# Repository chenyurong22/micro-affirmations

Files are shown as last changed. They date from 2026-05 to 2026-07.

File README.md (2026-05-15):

# µAffirmations
A microcontroller-based affection-giving MACHINE!

> [!IMPORTANT]
> This project is currently a work-in-progress, there __will__ be things that don't work, please bear with me will I work out the kinks!

# Table of Contents
- [Usage Guide](#usage-guide)
  - [Hardware](#hardware)
  - [Firmware](#firmware)
- [Project Updates](#project-updates)
- [Copyright and Licensing](#copyright-and-licensing)
- [Contact](#contact)

# Usage Guide
## Hardware
The PCB files can be found [here](/hw/pcb/RevB.zip), be sure of order a solder stencil too(ideally with a stencil unless you love hand-soldering 200+ SMD connections). The [BOM](/hw/pcb/micro-affirmations_BOM.csv) will provide you with a list of parts required. Due to the limited size on the PCB, many of the reference designators have been removed to save space. Because of this, you will likely need to have KiCAD running as you are placing components.

## Firmware
You will need access to an ST-Link programming device and have Platform IO installed via VS code. Once you're ready, upload the code by:
- Cloning the repository
- Open in VS code
- Connect the ST-Link programmer to your computer
- Connect the µAffirmations' programming port to the ST-Link programmer
- Ensure the µAffirmations board is powered
- Open the STM32 for VS Code extention
- Click __Upload__

<!--
### Message customisation
This device allows the user to create their own custom messages to be displayed on the LED matrix, to provide your messages, modify the following code found in [this](/path/to/file.c) file.

For axample:
```c
uint8_t someVar = 0;
```
-->

# Project Updates
## Hardware [RevB](https://github.com/i-Saac-IV/micro-affirmations/tree/v0.9.1)
After hardware tesing the following fixes have been made to the hardware design:
- Supercapcitor charging circuit, now uses a dedecated IC
- LED matrix layout, the LED spacing has been decreased
- LED brightness was assessed and appropriate resistor have been selected
- The overall PCB dimentions have shrunk to 70x40mm

## Hardware [RevA](https://github.com/i-Saac-IV/micro-affirmations/tree/v0.9.0)
Initial hardware design.

# Copyright and Licensing
See [licence](LICENSE) for in depth info.
<!--
This project uses the following third-party libraries:

- Lib ( License)

Copyright and license terms belong to their respective authors.

Contact me if anything here is incorrect.
-->

# Contact
If you'd like to get in touch, feel free to reach out!
<p>
  <a href="https://github.com/i-Saac-IV">
    
  </a>
  <a href="https://www.linkedin.com/in/isaac-pawley/">
    
  </a>
  <a href="https://www.instagram.com/i.saac.0100/">
    
  </a>
  <a href="mailto:75295202+i-Saac-IV@users.noreply.github.com">
    
  </a>
</p>

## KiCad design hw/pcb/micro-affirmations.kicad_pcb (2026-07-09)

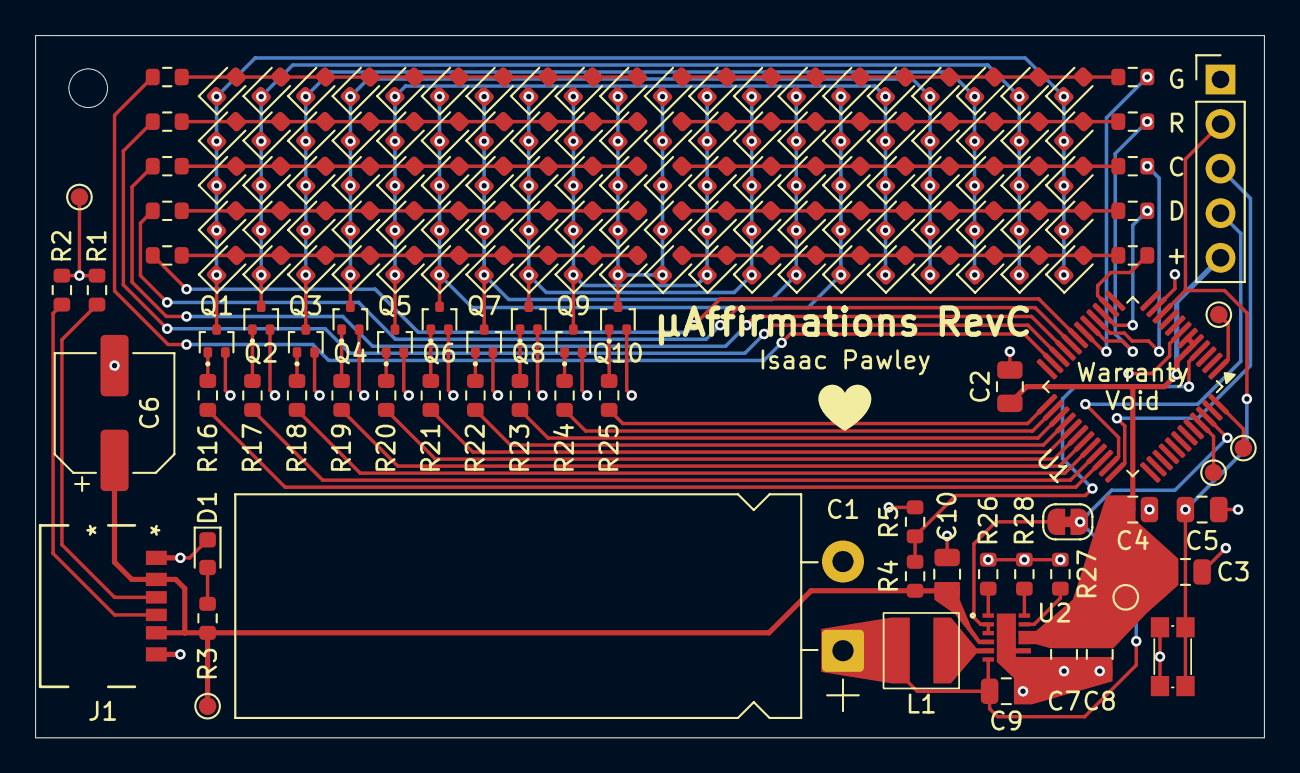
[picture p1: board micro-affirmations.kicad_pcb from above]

Board: 2 copper layers, 70.0 x 40.0 mm, 164 parts (1 on the bottom side), 70 nets.

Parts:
C1: 15F; CP_Radial_L32.0mm_D12.5mm_P5.00mm_Horizontal
C2: 4.7u; C_0805_2012Metric
C3, C4, C5: 100n; C_0805_2012Metric
C6: 100u; CP_Elec_6.3x5.4_Nichicon
C7, C8, C9, C10: 10u; C_0805_2012Metric
D1: CHARGE; D_0603_1608Metric
D5, D6, D7, D8, D9, D10, D11, D12, D13, D14, D15, D16, D17, D18, D19, D20, D21, D22, D23, D24, D25, D26, D27, D28, D29, D30, D31, D32, D33, D34, D35, D36, D37, D38, D39, D40, D41, D42, D43, D44, D45, D46, D47, D48, D49, D50, D51, D52, D53, D54, D55, D56, D57, D58, D59, D60, D61, D62, D63, D64, D65, D66, D67, D68, D69, D70, D71, D72, D73, D74, D75, D76, D77, D78, D79, D80, D81, D82, D83, D84, D85, D86, D87, D88, D89, D90, D91, D92, D93, D94, D95, D96, D97, D98, D99, D100, D101, D102, D103, D104: LED; D_0603_1608Metric
H1: MountingHole; MountingHole_2.2mm_M2
J1: USBC; 2171750001_MOL
J2: DEBUG; PinHeader_1x05_P2.54mm_Vertical
JP1: SolderJumper_2_Bridged; SolderJumper-2_P1.3mm_Bridged_RoundedPad1.0x1.5mm
L1: 2.2u; L_1616_4040Metric
Q1, Q2, Q3, Q4, Q5, Q6, Q7, Q8, Q9, Q10: NCH; SOT-416
R1, R2, R4: 5.1k; R_0603_1608Metric
R3: 1.5k; R_0603_1608Metric
R5: 10k; R_0603_1608Metric
R6, R7, R8, R9, R10, R11, R12, R13, R14, R15: 820; R_0603_1608Metric
R16, R17, R18, R19, R20, R21, R22, R23, R24, R25: 100; R_0603_1608Metric
R26: 4.75k; R_0603_1608Metric
R27: 75.0k; R_0603_1608Metric
R28: 13.0k; R_0603_1608Metric
SW1: RST; TL1030_A
TP2, TP3, TP4, TP5, TP6, TP7, TP8: TestPoint; TestPoint_Pad_D1.0mm
U1: STM32C031C6Tx; LQFP-48_7x7mm_P0.5mm
U2: TPS61094; WSON_94DSSR_TEX

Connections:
+3V3: C2.1, C3.1, C4.1, C7.1, C8.1, J2.5, TP3.1 (1_1), U1.5 (VREF+), U1.6 (VDD), U2.9 (VOUT), U2.10 (VOUT)
+5V: C6.1, C10.1, J1.A9 (VBUS), J1.B9 (VBUS), R3.1, R4.2, TP2.1 (1_1), U2.4 (VIN)
/CHARGE_SENSE: R4.1, R5.2, U1.4 (PF3)
/DEBUG_SWCLK: J2.3, U1.36 (PA14)
/DEBUG_SWDIO: J2.4, U1.35 (PA13)
/MATRIX_A0: R6.1, U1.23 (PB11)
/MATRIX_A1: R7.1, U1.22 (PB10)
/MATRIX_A2: R8.1, U1.21 (PB2)
/MATRIX_A3: R9.1, U1.20 (PB1)
/MATRIX_A4: R10.1, U1.19 (PB0)
/MATRIX_A5: R11.1, U1.18 (PA7)
/MATRIX_A6: R12.1, U1.17 (PA6)
/MATRIX_A7: R13.1, U1.16 (PA5)
/MATRIX_A8: R14.1, U1.15 (PA4)
/MATRIX_A9: R15.1, U1.14 (PA3)
/MATRIX_K0: R16.1, U1.34 (PA12)
/MATRIX_K1: R17.1, U1.33 (PA11)
/MATRIX_K2: R18.1, U1.32 (PA10)
/MATRIX_K3: R19.1, U1.31 (PC7)
/MATRIX_K4: R20.1, U1.30 (PC6)
/MATRIX_K5: R21.1, U1.29 (PA9)
/MATRIX_K6: R22.1, U1.28 (PA8)
/MATRIX_K7: R23.1, U1.27 (PB15)
/MATRIX_K8: R24.1, U1.26 (PB14)
/MATRIX_K9: R25.1, U1.25 (PB13)
/NRST: C5.1, J2.2, SW1.2, U1.10 (PF2)
CAP_VOLT: C1.1, C9.1, JP1.1 (A), L1.2, U1.46 (PB7), U2.6 (SUP)
GND: C1.2, C2.2, C3.2, C4.2, C5.2, C6.2, C7.2, C8.2, C9.2, C10.2, D1.1 (K), J1.A12 (GND), J1.B12 (GND), J2.1, Q1.2 (S), Q2.2 (S), Q3.2 (S), Q4.2 (S), Q5.2 (S), Q6.2 (S), Q7.2 (S), Q8.2 (S), Q9.2 (S), Q10.2 (S), R1.2, R2.2, R5.1, R26.1, R27.1, R28.1, SW1.1, TP8.1 (1_1), U1.7 (VSS), U2.7 (PGND), U2.8 (AGND), U2.13
unnamed: D1.2 (A), R3.2
unnamed: D5.2 (A), D6.2 (A), D7.2 (A), D8.2 (A), D9.2 (A), D10.2 (A), D11.2 (A), D12.2 (A), D13.2 (A), D14.2 (A), R6.2
unnamed: D10.1 (K), D20.1 (K), D30.1 (K), D40.1 (K), D50.1 (K), D60.1 (K), D70.1 (K), D80.1 (K), D90.1 (K), D100.1 (K), Q6.3 (D)
unnamed: D15.2 (A), D16.2 (A), D17.2 (A), D18.2 (A), D19.2 (A), D20.2 (A), D21.2 (A), D22.2 (A), D23.2 (A), D24.2 (A), R7.2
unnamed: D5.1 (K), D15.1 (K), D25.1 (K), D35.1 (K), D45.1 (K), D55.1 (K), D65.1 (K), D75.1 (K), D85.1 (K), D95.1 (K), Q1.3 (D)
unnamed: D6.1 (K), D16.1 (K), D26.1 (K), D36.1 (K), D46.1 (K), D56.1 (K), D66.1 (K), D76.1 (K), D86.1 (K), D96.1 (K), Q2.3 (D)
unnamed: D7.1 (K), D17.1 (K), D27.1 (K), D37.1 (K), D47.1 (K), D57.1 (K), D67.1 (K), D77.1 (K), D87.1 (K), D97.1 (K), Q3.3 (D)
unnamed: D8.1 (K), D18.1 (K), D28.1 (K), D38.1 (K), D48.1 (K), D58.1 (K), D68.1 (K), D78.1 (K), D88.1 (K), D98.1 (K), Q4.3 (D)
unnamed: D9.1 (K), D19.1 (K), D29.1 (K), D39.1 (K), D49.1 (K), D59.1 (K), D69.1 (K), D79.1 (K), D89.1 (K), D99.1 (K), Q5.3 (D)
unnamed: D25.2 (A), D26.2 (A), D27.2 (A), D28.2 (A), D29.2 (A), D30.2 (A), D31.2 (A), D32.2 (A), D33.2 (A), D34.2 (A), R8.2
unnamed: D35.2 (A), D36.2 (A), D37.2 (A), D38.2 (A), D39.2 (A), D40.2 (A), D41.2 (A), D42.2 (A), D43.2 (A), D44.2 (A), R9.2
unnamed: D45.2 (A), D46.2 (A), D47.2 (A), D48.2 (A), D49.2 (A), D50.2 (A), D51.2 (A), D52.2 (A), D53.2 (A), D54.2 (A), R10.2
unnamed: D55.2 (A), D56.2 (A), D57.2 (A), D58.2 (A), D59.2 (A), D60.2 (A), D61.2 (A), D62.2 (A), D63.2 (A), D64.2 (A), R11.2
unnamed: D65.2 (A), D66.2 (A), D67.2 (A), D68.2 (A), D69.2 (A), D70.2 (A), D71.2 (A), D72.2 (A), D73.2 (A), D74.2 (A), R12.2
unnamed: D75.2 (A), D76.2 (A), D77.2 (A), D78.2 (A), D79.2 (A), D80.2 (A), D81.2 (A), D82.2 (A), D83.2 (A), D84.2 (A), R13.2
unnamed: D85.2 (A), D86.2 (A), D87.2 (A), D88.2 (A), D89.2 (A), D90.2 (A), D91.2 (A), D92.2 (A), D93.2 (A), D94.2 (A), R14.2
unnamed: D95.2 (A), D96.2 (A), D97.2 (A), D98.2 (A), D99.2 (A), D100.2 (A), D101.2 (A), D102.2 (A), D103.2 (A), D104.2 (A), R15.2
unnamed: D11.1 (K), D21.1 (K), D31.1 (K), D41.1 (K), D51.1 (K), D61.1 (K), D71.1 (K), D81.1 (K), D91.1 (K), D101.1 (K), Q7.3 (D)
unnamed: D12.1 (K), D22.1 (K), D32.1 (K), D42.1 (K), D52.1 (K), D62.1 (K), D72.1 (K), D82.1 (K), D92.1 (K), D102.1 (K), Q8.3 (D)
unnamed: D13.1 (K), D23.1 (K), D33.1 (K), D43.1 (K), D53.1 (K), D63.1 (K), D73.1 (K), D83.1 (K), D93.1 (K), D103.1 (K), Q9.3 (D)
unnamed: D14.1 (K), D24.1 (K), D34.1 (K), D44.1 (K), D54.1 (K), D64.1 (K), D74.1 (K), D84.1 (K), D94.1 (K), D104.1 (K), Q10.3 (D)
unnamed: J1.A5 (CC1), R1.1
unnamed: J1.B5 (CC2), R2.1
unnamed: JP1.2 (B), U2.2 (MODE), U2.3 (EN)
unnamed: Q1.1 (G), R16.2
unnamed: Q2.1 (G), R17.2
unnamed: Q3.1 (G), R18.2
unnamed: Q4.1 (G), R19.2
unnamed: Q5.1 (G), R20.2
unnamed: Q6.1 (G), R21.2
unnamed: Q7.1 (G), R22.2
unnamed: Q8.1 (G), R23.2
unnamed: Q9.1 (G), R24.2
unnamed: Q10.1 (G), R25.2
unnamed: TP7.1 (1_1), U1.11 (PA0)
unnamed: TP5.1 (1_1), U1.45 (PB6)
unnamed: TP4.1 (1_1), U1.48 (PB9)
unnamed: TP6.1 (1_1), U1.1 (PC13)
unnamed: R27.2, U2.11 (ICHG)
unnamed: R26.2, U2.1 (OSEL)
unnamed: L1.1, U2.5 (SW)
unnamed: R28.2, U2.12 (VCHG)

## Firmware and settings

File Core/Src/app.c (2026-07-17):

/*

File:   app.h
Author: Isaac Pawley

*/

#include "app.h"

#include "adc.h"
#include "stm32c0xx_hal.h"

typedef enum
{
    ADC_RANDOM,
    ADC_CAP_VOLT
} ADC_Input_t;

uint16_t ADC_Read(ADC_Input_t input)
{
    uint16_t random_value = 0;
    uint16_t cap_voltage_value = 0;

    HAL_ADC_Start(&hadc1);

    // Rank 1: PA1 RANDOM
    if (HAL_ADC_PollForConversion(&hadc1, 10) == HAL_OK)
    {
        random_value = HAL_ADC_GetValue(&hadc1);
    }

    // Rank 2: PB7 CAP_VOLT
    if (HAL_ADC_PollForConversion(&hadc1, 10) == HAL_OK)
    {
        cap_voltage_value = HAL_ADC_GetValue(&hadc1);
    }

    HAL_ADC_Stop(&hadc1);

    if (input == ADC_RANDOM)
    {
        return random_value;
    }
    else
    {
        return cap_voltage_value;
    }
}

#include "matrix.h"
#include "nanoGL.h"

void app_main(void) {

    uint32_t now = 0;
    uint32_t next = 0;

    nanoGL_clear();

    static int16_t scrollX = PHYSICAL_COLS;

    while (1) {
        matrix_updateMultiplex();

        if (HAL_GetTick() > next) {
            next = HAL_GetTick() + 75;
            nanoGL_clear();

            nanoGL_drawString(scrollX, 0, "Here is a long message...", &Font_5x5);
            scrollX--;
            
            if (scrollX < -nanoGL_stringWidth("Here is a long message...", &Font_5x5)) {
                scrollX = PHYSICAL_COLS;
            }
        }

        now = HAL_GetTick();
        while (HAL_GetTick() < now + 1) {};
    }    
}

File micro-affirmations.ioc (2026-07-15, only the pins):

Mcu.UserName=STM32C031C6Tx
PA1.GPIO_Label=RANDOM
PA1.Signal=ADC1_IN1
PA10.GPIO_Label=MATRIX_K2
PA10.Signal=GPIO_Output
PA13.Signal=DEBUG_SWDIO
PA14-BOOT0.Signal=DEBUG_SWCLK
PA3.GPIO_Label=MATRIX_A9
PA3.Signal=GPIO_Output
PA4.GPIO_Label=MATRIX_A8
PA4.Signal=GPIO_Output
PA5.GPIO_Label=MATRIX_A7
PA5.Signal=GPIO_Output
PA6.GPIO_Label=MATRIX_A6
PA6.Signal=GPIO_Output
PA7.GPIO_Label=MATRIX_A5
PA7.Signal=GPIO_Output
PA8.GPIO_Label=MATRIX_K6
PA8.Signal=GPIO_Output
PA9.GPIO_Label=MATRIX_K5
PA9.Signal=GPIO_Output
PB0.GPIO_Label=MATRIX_A4
PB0.Signal=GPIO_Output
PB1.GPIO_Label=MATRIX_A3
PB1.Signal=GPIO_Output
PB10.GPIO_Label=MATRIX_A1
PB10.Signal=GPIO_Output
PB11.GPIO_Label=MATRIX_A0
PB11.Signal=GPIO_Output
PB13.GPIO_Label=MATRIX_K9
PB13.Signal=GPIO_Output
PB14.GPIO_Label=MATRIX_K8
PB14.Signal=GPIO_Output
PB15.GPIO_Label=MATRIX_K7
PB15.Signal=GPIO_Output
PB2.GPIO_Label=MATRIX_A2
PB2.Signal=GPIO_Output
PB7.GPIO_Label=CAP_VOLT
PB7.Signal=GPIO_Analog
PC6.GPIO_Label=MATRIX_K4
PC6.Signal=GPIO_Output
PC7.GPIO_Label=MATRIX_K3
PC7.Signal=GPIO_Output
PF3.GPIO_Label=CHARGE_SENSE
PF3.Signal=GPIO_Input

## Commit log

2026-05-11 chore: added charger footprints
2026-05-11 chore: updated schematic to have correctly sized current limiting resistors
    [led-matrix.kicad_sch]
2026-05-11 chore: redesigned pcb, new capacitor charger and smaller matrix
    [micro-affirmations.kicad_pcb, micro-affirmations.kicad_sch]
2026-05-11 chore: updated schematics to show true part numbers
    [led-matrix.kicad_sch, micro-affirmations.kicad_sch, supercapacitor-charger.kicad_sch]
2026-07-09 fix: rewired swd pins and supercap changer enable pins
    [micro-affirmations.kicad_pcb, micro-affirmations.kicad_sch, supercapacitor-charger.kicad_sch]
2026-07-16 chore: minor fixes to function names
    [matrix.c]
